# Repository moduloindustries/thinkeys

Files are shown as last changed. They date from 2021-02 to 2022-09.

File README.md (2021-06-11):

View this project on [CADLAB.io](https://cadlab.io/project/24445). 

ThinKeys
========
Split ortholinear custom replacement keyboard with TrackPoint for ThinkPad laptops.

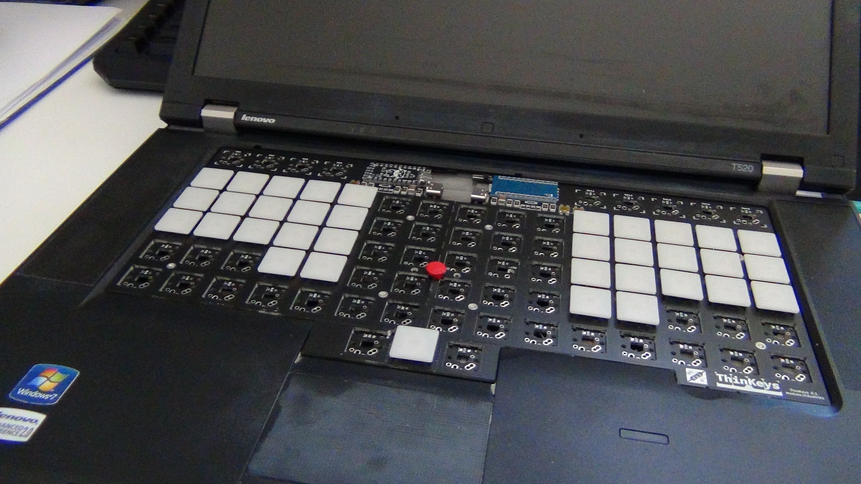
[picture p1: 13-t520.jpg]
in t520

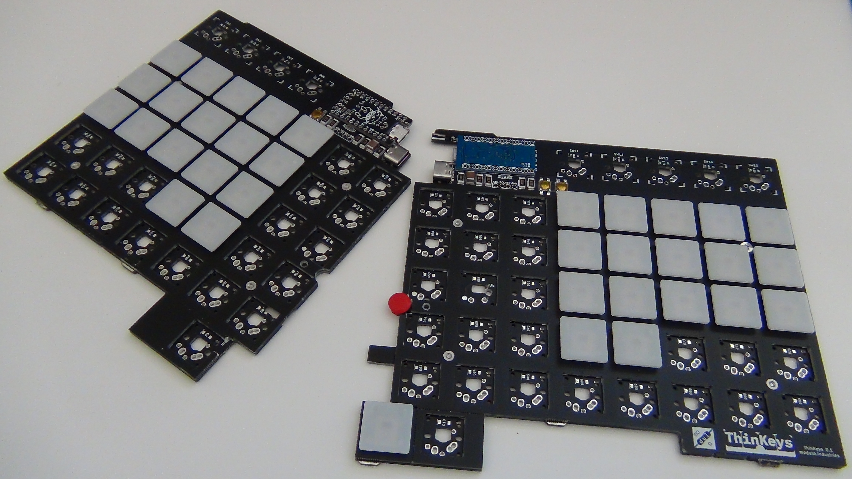
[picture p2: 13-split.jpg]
split


Layout can be mapped as desired with QMK.

Other physical layouts will be offered if there is enough demand for them.

Videos
------
- [Playlist (YouTube)](https://www.youtube.com/playlist?list=PLA83yaoqEOKUAF3hhw5IN6eBIaD0fTjDs)

Compatibility
-------------
The first model is for Lenovo ThinkPads T410-T430, T510-T530, W510-W530, and
X220-X230 (including s, i, and t suffixed variants).

Later model support planned for X230s-X270, T431s-T450s/T440(p)-T460(p) and
beyond.

Goals
-----
- [X] TrackPoint
- [X] Split for external/desktop use (connect via USB Type-C)
- [X] Ortholinear
- [ ] ~~RGB LED Backlight (ThinkLight infeasible)~~ No backlight in the first
      version, maybe next time
- [X] USB Connection
- [X] Power Button
- [X] Socketable Pro Micro (or compatible)

Chat
----
Join via Matrix: https://matrix.to/#/!igsJfJkAlUganwyDzE:librem.one?via=librem.one

Join via Discord: https://discord.gg/MA2DBqRyEK

Low Profile Keyboards Discord: https://discord.gg/yhGEvATCFs

Pineapples
----------
Inspiration and some design from https://github.com/saoto28/pineapple60

Older models like xx20/xx30 have a lot more keyboard thickness (height?) than
newer ones like T460s/T470s, so lid closing clearance is not expected be an
issue.

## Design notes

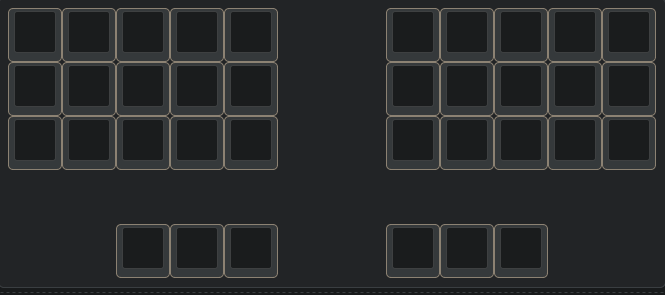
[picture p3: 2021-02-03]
23-corne.png

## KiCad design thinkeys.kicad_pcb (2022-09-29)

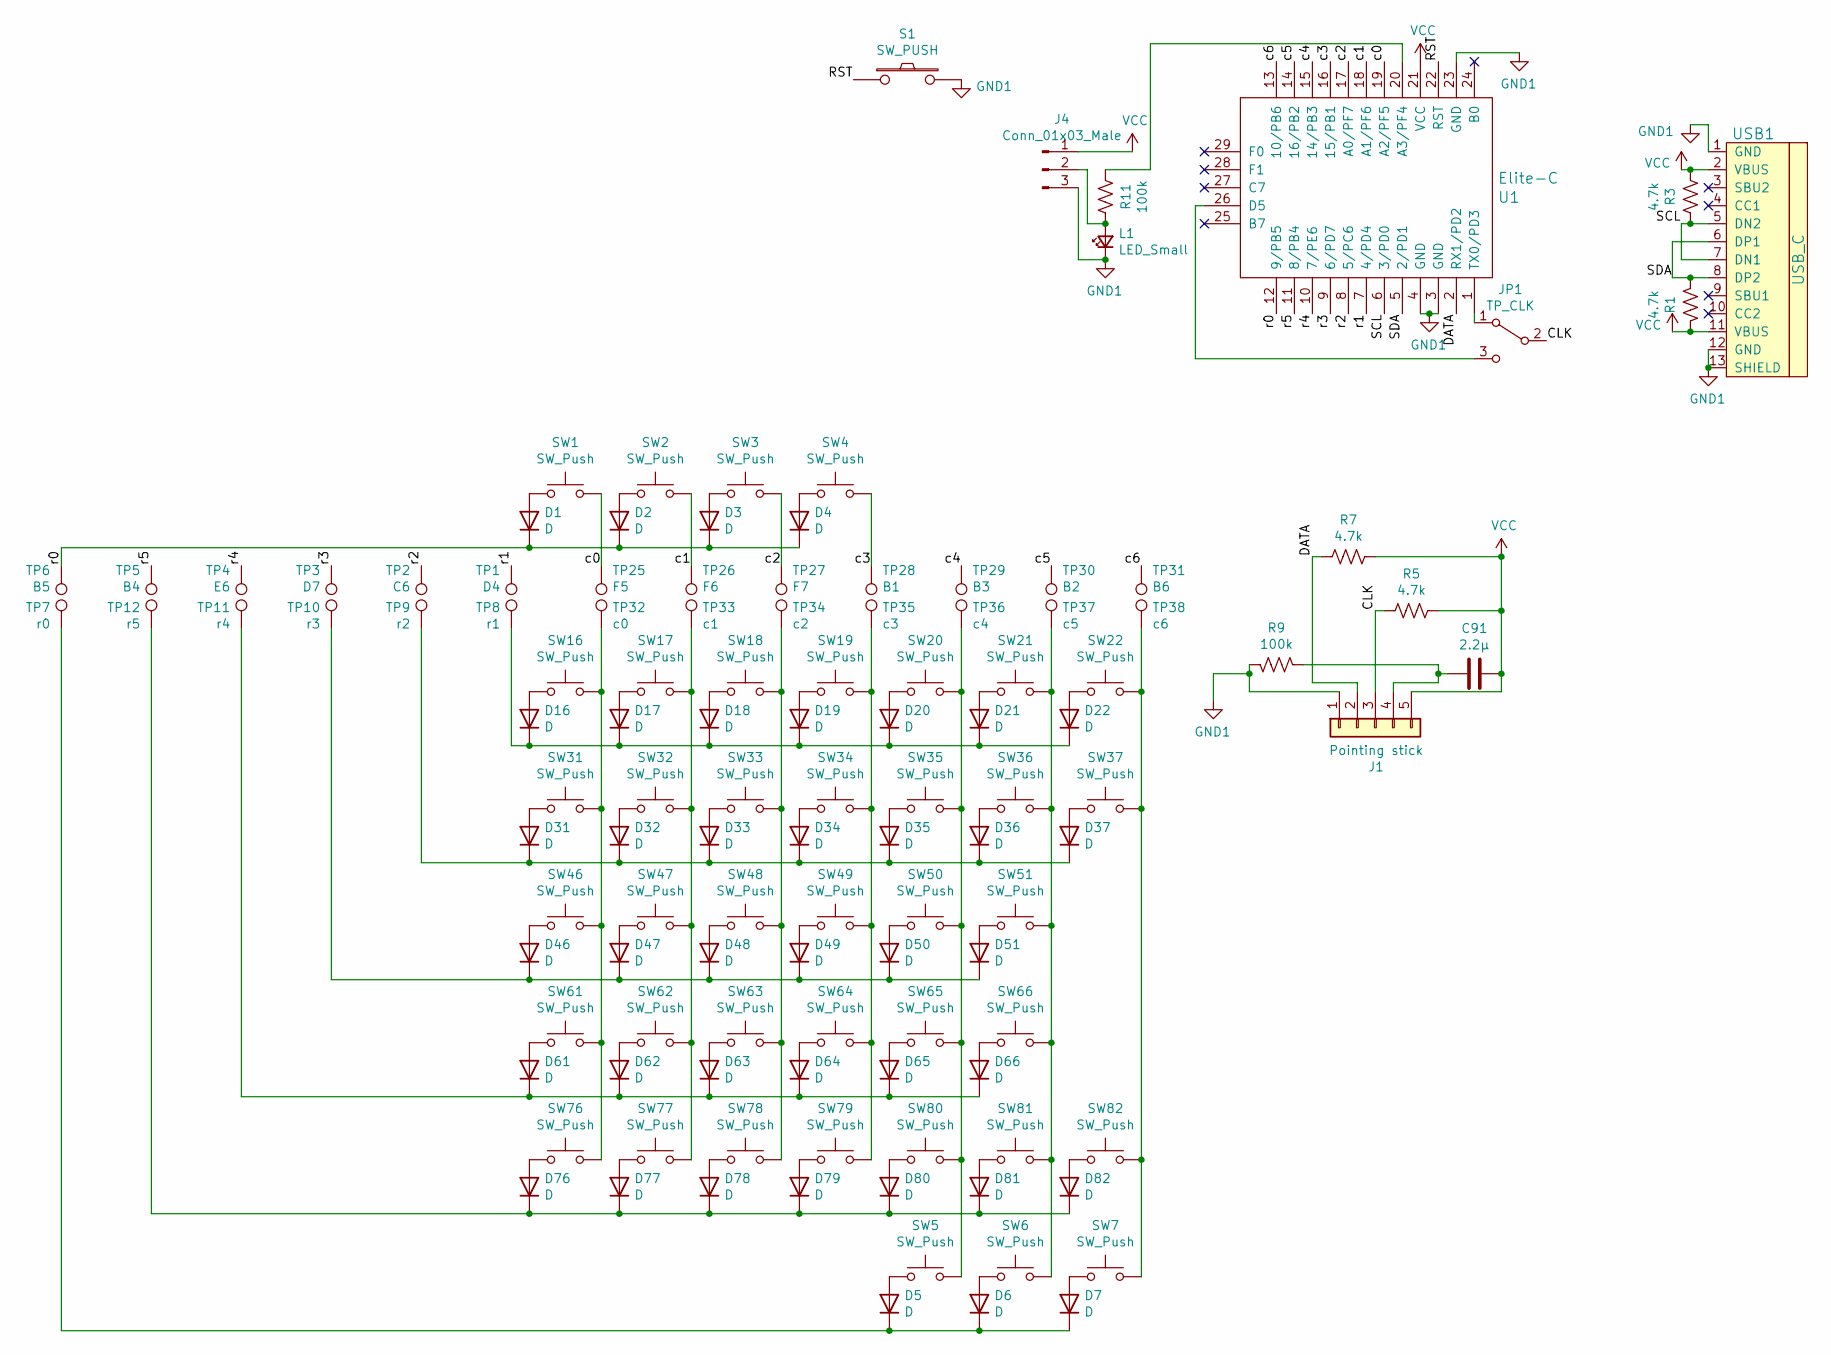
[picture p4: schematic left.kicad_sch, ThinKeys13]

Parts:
C91: 2.2µ; C_1206_3216Metric_Pad1.33x1.80mm_HandSolder; LCSC Part C50254
D1, D2, D3, D4, D5, D6, D7, D16, D17, D18, D19, D20, D21, D22, D31, D32, D33, D34, D35, D36, D37, D46, D47, D48, D49, D50, D51, D61, D62, D63, D64, D65, D66, D76, D77, D78, D79, D80, D81, D82: D; D_SOD-123; LCSC Part C64898
J1: Pointing stick; SK8707-01
J4: Conn_01x03_Male; PinHeader_1x03_P2.00mm_Vertical_SMD_Pin1Left
JP1: TP_CLK; SolderJumper-3_P1.3mm_Open_RoundedPad1.0x1.5mm_NumberLabels
L1: LED_Small; LED_0805_2012Metric_Castellated; LCSC Part C72043
R1, R3, R5, R7: 4.7k; R_1206_3216Metric_Pad1.30x1.75mm_HandSolder; LCSC Part C17936
R9: 100k; R_1206_3216Metric_Pad1.30x1.75mm_HandSolder; LCSC Part C17900
R11: 100k; R_1206_3216Metric_Pad1.30x1.75mm_HandSolder; LCSC Part C17936
S1: SW_PUSH; SW_SPST_EVQQ2; LCSC Part C713483
SW1, SW2, SW3, SW4, SW5, SW6, SW7, SW16, SW17, SW18, SW19, SW20, SW21, SW22, SW31, SW32, SW33, SW34, SW35, SW36, SW37, SW46, SW47, SW48, SW49, SW50, SW51, SW61, SW62, SW63, SW64, SW65, SW66, SW76, SW77, SW78, SW79, SW80, SW81, SW82: SW_Push; SW_MX-ALPS-ChocV1_V2-X-PG1280_PCB
TP1: D4; SMDPad_4.0x2.0mm
TP2: C6; SMDPad_4.0x2.0mm
TP3: D7; SMDPad_4.0x2.0mm
TP4: E6; SMDPad_4.0x2.0mm
TP5: B4; SMDPad_4.0x2.0mm
TP6: B5; SMDPad_4.0x2.0mm
TP7: r0; THTPad_4.0x4.0mm_Drill2.0mm
TP8: r1; THTPad_4.0x4.0mm_Drill2.0mm
TP9: r2; THTPad_4.0x4.0mm_Drill2.0mm
TP10: r3; THTPad_4.0x4.0mm_Drill2.0mm
TP11: r4; THTPad_4.0x4.0mm_Drill2.0mm
TP12: r5; THTPad_4.0x4.0mm_Drill2.0mm
TP25: F5; SMDPad_4.0x2.0mm
TP26: F6; SMDPad_4.0x2.0mm
TP27: F7; SMDPad_4.0x2.0mm
TP28: B1; SMDPad_4.0x2.0mm
TP29: B3; SMDPad_4.0x2.0mm
TP30: B2; SMDPad_4.0x2.0mm
TP31: B6; SMDPad_4.0x2.0mm
TP32: c0; THTPad_4.0x4.0mm_Drill2.0mm
TP33: c1; THTPad_4.0x4.0mm_Drill2.0mm
TP34: c2; THTPad_4.0x4.0mm_Drill2.0mm
TP35: c3; THTPad_4.0x4.0mm_Drill2.0mm
TP36: c4; THTPad_4.0x4.0mm_Drill2.0mm
TP37: c5; THTPad_4.0x4.0mm_Drill2.0mm
TP38: c6; THTPad_4.0x4.0mm_Drill2.0mm
U1: Elite-C
USB1: USB_C; HRO-TYPE-C-31-M-12; LCSC Part C165948

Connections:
/left/CLK: J1.3, JP1.2 (B), R5.1
/left/DATA: J1.2, R7.1, U1.2 (RX1/PD2)
/left/RST: S1.1, U1.22 (RST)
/left/SCL: R3.1, U1.6 (3/PD0), USB1.5 (DN2), USB1.7 (DN1)
/left/SDA: R1.1, U1.5 (2/PD1), USB1.6 (DP1), USB1.8 (DP2)
/left/c0: SW1.2, TP25.1, U1.19 (A2/PF5)
/left/c1: SW2.2, TP26.1, U1.18 (A1/PF6)
/left/c2: SW3.2, TP27.1, U1.17 (A0/PF7)
/left/c3: SW4.2, TP28.1, U1.16 (15/PB1)
/left/c4: TP29.1, U1.15 (14/PB3)
/left/c5: TP30.1, U1.14 (16/PB2)
/left/c6: TP31.1, U1.13 (10/PB6)
/left/r0: D1.1 (K), D2.1 (K), D3.1 (K), D4.1 (K), TP6.1, U1.12 (9/PB5)
/left/r1: TP1.1, U1.7 (4/PD4)
/left/r2: TP2.1, U1.8 (5/PC6)
/left/r3: TP3.1, U1.9 (6/PD7)
/left/r4: TP4.1, U1.10 (7/PE6)
/left/r5: TP5.1, U1.11 (8/PB4)
GND1: J1.1, J4.3, L1.1 (K), R9.2, S1.2, U1.3 (GND), U1.4 (GND), U1.23 (GND), USB1.1 (GND), USB1.12 (GND), USB1.13 (SHIELD)
unnamed: C91.1, J1.4, R9.1
unnamed: D1.2 (A), SW1.1
unnamed: D2.2 (A), SW2.1
unnamed: D3.2 (A), SW3.1
unnamed: D4.2 (A), SW4.1
unnamed: D5.1 (K), D6.1 (K), D7.1 (K), TP7.1
unnamed: D5.2 (A), SW5.1
unnamed: D6.2 (A), SW6.1
unnamed: D7.2 (A), SW7.1
unnamed: D16.1 (K), D17.1 (K), D18.1 (K), D19.1 (K), D20.1 (K), D21.1 (K), D22.1 (K), TP8.1
unnamed: D16.2 (A), SW16.1
unnamed: D17.2 (A), SW17.1
unnamed: D18.2 (A), SW18.1
unnamed: D19.2 (A), SW19.1
unnamed: D20.2 (A), SW20.1
unnamed: D21.2 (A), SW21.1
unnamed: D22.2 (A), SW22.1
unnamed: D31.1 (K), D32.1 (K), D33.1 (K), D34.1 (K), D35.1 (K), D36.1 (K), D37.1 (K), TP9.1
unnamed: D31.2 (A), SW31.1
unnamed: D32.2 (A), SW32.1
unnamed: D33.2 (A), SW33.1
unnamed: D34.2 (A), SW34.1
unnamed: D35.2 (A), SW35.1
unnamed: D36.2 (A), SW36.1
unnamed: D37.2 (A), SW37.1
unnamed: D46.1 (K), D47.1 (K), D48.1 (K), D49.1 (K), D50.1 (K), D51.1 (K), TP10.1
unnamed: D46.2 (A), SW46.1
unnamed: D47.2 (A), SW47.1
unnamed: D48.2 (A), SW48.1
unnamed: D49.2 (A), SW49.1
unnamed: D50.2 (A), SW50.1
unnamed: D51.2 (A), SW51.1
unnamed: D61.1 (K), D62.1 (K), D63.1 (K), D64.1 (K), D65.1 (K), D66.1 (K), TP11.1
unnamed: D61.2 (A), SW61.1
unnamed: D62.2 (A), SW62.1
unnamed: D63.2 (A), SW63.1
unnamed: D64.2 (A), SW64.1
unnamed: D65.2 (A), SW65.1
unnamed: D66.2 (A), SW66.1
unnamed: D76.1 (K), D77.1 (K), D78.1 (K), D79.1 (K), D80.1 (K), D81.1 (K), D82.1 (K), TP12.1
unnamed: D76.2 (A), SW76.1
unnamed: D77.2 (A), SW77.1
unnamed: D78.2 (A), SW78.1
unnamed: D79.2 (A), SW79.1
unnamed: D80.2 (A), SW80.1
unnamed: D81.2 (A), SW81.1
unnamed: D82.2 (A), SW82.1
unnamed: J4.2, L1.2 (A), R11.2
unnamed: JP1.1 (A), U1.1 (TX0/PD3)
unnamed: JP1.3 (C), U1.26 (D5)
unnamed: R11.1, U1.20 (A3/PF4)
unnamed: SW16.2, SW31.2, SW46.2, SW61.2, SW76.2, TP32.1
unnamed: SW17.2, SW32.2, SW47.2, SW62.2, SW77.2, TP33.1
unnamed: SW18.2, SW33.2, SW48.2, SW63.2, SW78.2, TP34.1
unnamed: SW19.2, SW34.2, SW49.2, SW64.2, SW79.2, TP35.1
unnamed: SW5.2, SW20.2, SW35.2, SW50.2, SW65.2, SW80.2, TP36.1
unnamed: SW6.2, SW21.2, SW36.2, SW51.2, SW66.2, SW81.2, TP37.1
unnamed: SW7.2, SW22.2, SW37.2, SW82.2, TP38.1
VCC: C91.2, J1.5, J4.1, R1.2, R3.2, R5.2, R7.2, U1.21 (VCC), USB1.2 (VBUS), USB1.11 (VBUS)

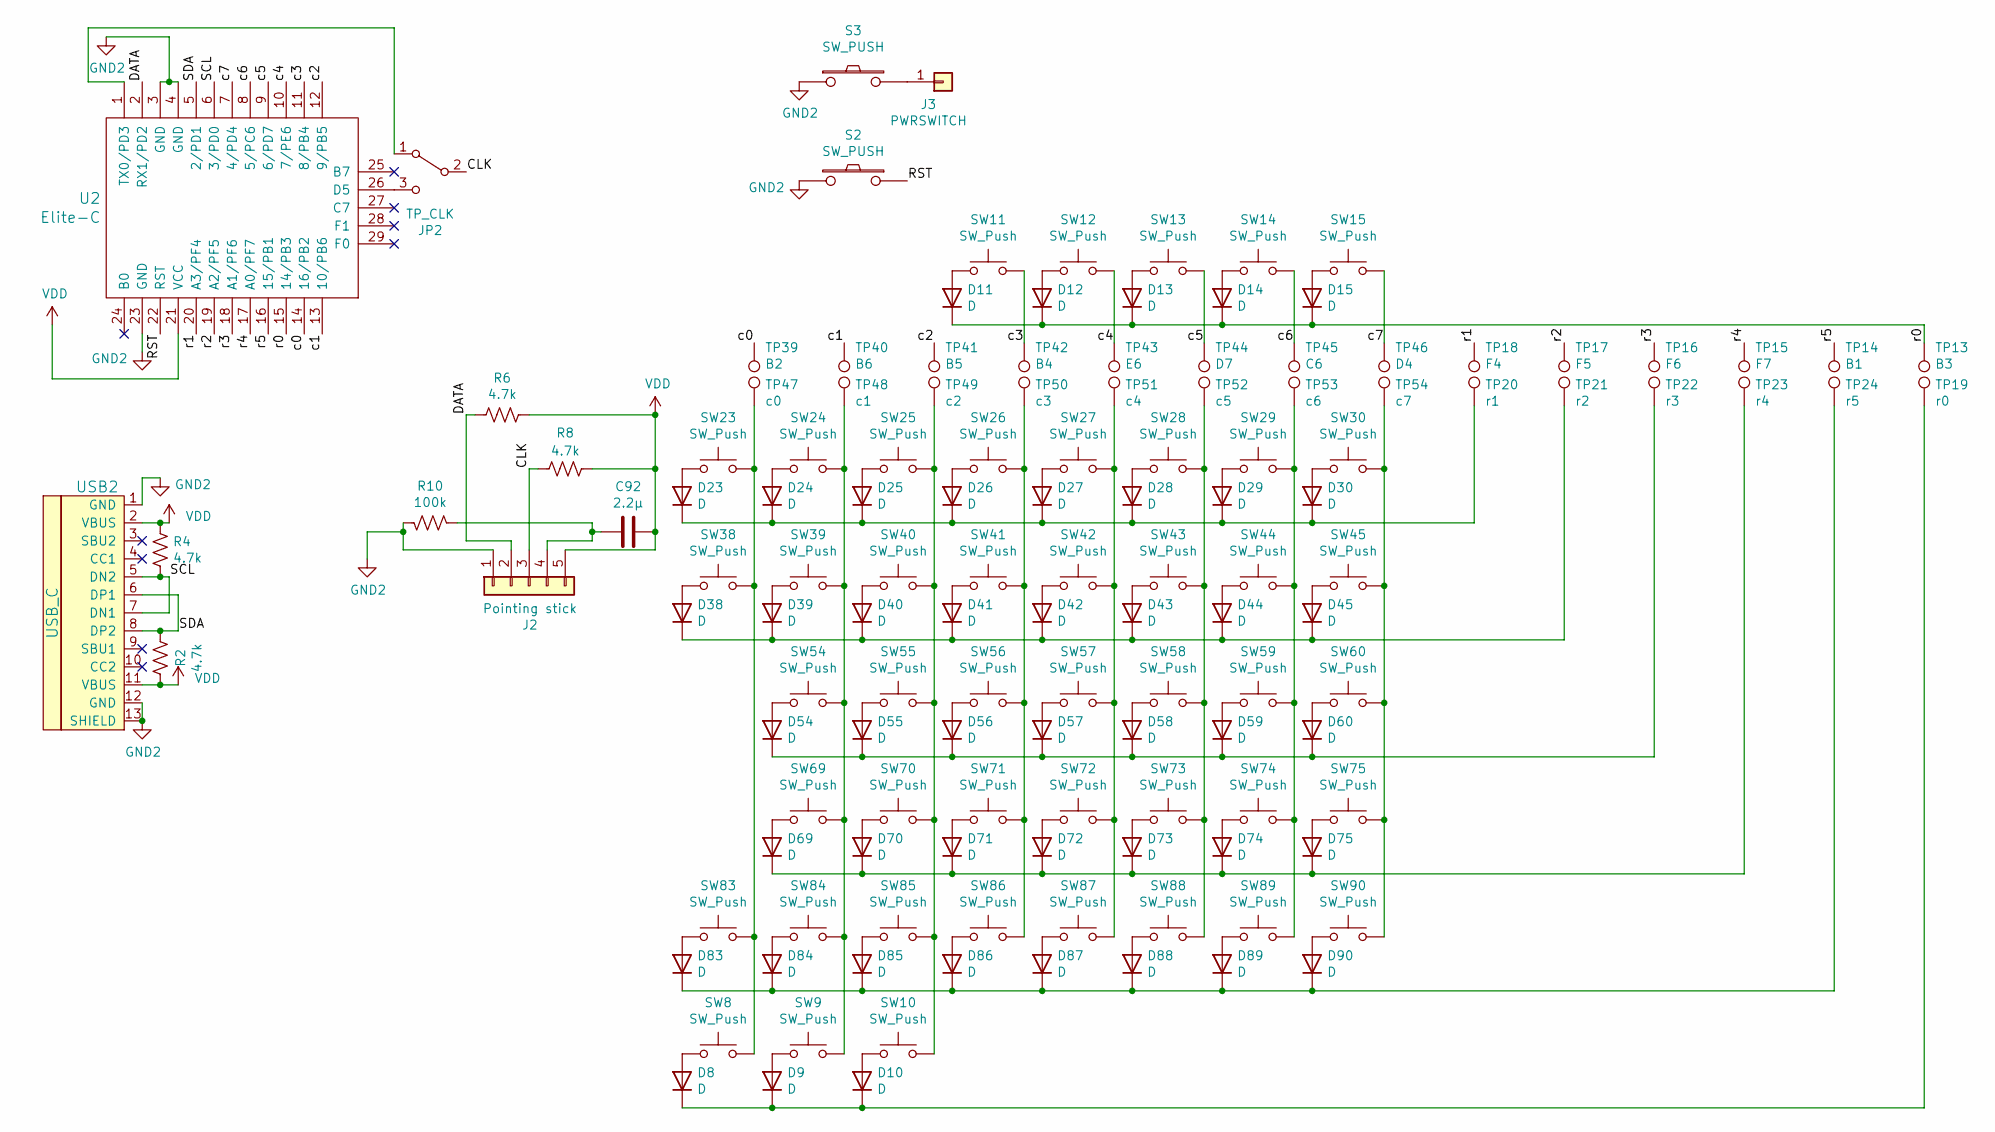
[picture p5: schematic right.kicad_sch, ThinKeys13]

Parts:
C92: 2.2µ; C_1206_3216Metric_Pad1.33x1.80mm_HandSolder; LCSC Part C50254
D8, D9, D10, D11, D12, D13, D14, D15, D23, D24, D25, D26, D27, D28, D29, D30, D38, D39, D40, D41, D42, D43, D44, D45, D54, D55, D56, D57, D58, D59, D60, D69, D70, D71, D72, D73, D74, D75, D83, D84, D85, D86, D87, D88, D89, D90: D; D_SOD-123; LCSC Part C64898
J2: Pointing stick; SK8707-01
J3: PWRSWITCH; PinHeader_1x01_P2.54mm_Horizontal
JP2: TP_CLK; SolderJumper-3_P1.3mm_Open_RoundedPad1.0x1.5mm_NumberLabels
R2, R4, R6, R8: 4.7k; R_1206_3216Metric_Pad1.30x1.75mm_HandSolder; LCSC Part C17936
R10: 100k; R_1206_3216Metric_Pad1.30x1.75mm_HandSolder; LCSC Part C17900
S2, S3: SW_PUSH; SW_SPST_EVQQ2; LCSC Part C713483
SW8, SW9, SW10, SW11, SW12, SW13, SW14, SW15, SW23, SW24, SW25, SW26, SW27, SW28, SW29, SW30, SW38, SW39, SW40, SW41, SW42, SW43, SW44, SW45, SW54, SW55, SW56, SW57, SW58, SW59, SW60, SW69, SW70, SW71, SW72, SW73, SW74, SW75, SW83, SW84, SW85, SW86, SW87, SW88, SW89, SW90: SW_Push; SW_MX-ALPS-ChocV1_V2-X-PG1280_PCB
TP13: B3; SMDPad_4.0x2.0mm
TP14: B1; SMDPad_4.0x2.0mm
TP15: F7; SMDPad_4.0x2.0mm
TP16: F6; SMDPad_4.0x2.0mm
TP17: F5; SMDPad_4.0x2.0mm
TP18: F4; SMDPad_4.0x2.0mm
TP19: r0; THTPad_4.0x4.0mm_Drill2.0mm
TP20: r1; THTPad_4.0x4.0mm_Drill2.0mm
TP21: r2; THTPad_4.0x4.0mm_Drill2.0mm
TP22: r3; THTPad_4.0x4.0mm_Drill2.0mm
TP23: r4; THTPad_4.0x4.0mm_Drill2.0mm
TP24: r5; THTPad_4.0x4.0mm_Drill2.0mm
TP39: B2; SMDPad_4.0x2.0mm
TP40: B6; SMDPad_4.0x2.0mm
TP41: B5; SMDPad_4.0x2.0mm
TP42: B4; SMDPad_4.0x2.0mm
TP43: E6; SMDPad_4.0x2.0mm
TP44: D7; SMDPad_4.0x2.0mm
TP45: C6; SMDPad_4.0x2.0mm
TP46: D4; SMDPad_4.0x2.0mm
TP47: c0; THTPad_4.0x4.0mm_Drill2.0mm
TP48: c1; THTPad_4.0x4.0mm_Drill2.0mm
TP49: c2; THTPad_4.0x4.0mm_Drill2.0mm
TP50: c3; THTPad_4.0x4.0mm_Drill2.0mm
TP51: c4; THTPad_4.0x4.0mm_Drill2.0mm
TP52: c5; THTPad_4.0x4.0mm_Drill2.0mm
TP53: c6; THTPad_4.0x4.0mm_Drill2.0mm
TP54: c7; THTPad_4.0x4.0mm_Drill2.0mm
U2: Elite-C
USB2: USB_C; HRO-TYPE-C-31-M-12; LCSC Part C165948

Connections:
/right/CLK: J2.3, JP2.2 (B), R8.1
/right/DATA: J2.2, R6.1, U2.2 (RX1/PD2)
/right/RST: S2.1, U2.22 (RST)
/right/SCL: R4.1, U2.6 (3/PD0), USB2.5 (DN2), USB2.7 (DN1)
/right/SDA: R2.1, U2.5 (2/PD1), USB2.6 (DP1), USB2.8 (DP2)
/right/c0: TP39.1, U2.14 (16/PB2)
/right/c1: TP40.1, U2.13 (10/PB6)
/right/c2: TP41.1, U2.12 (9/PB5)
/right/c3: SW11.2, TP42.1, U2.11 (8/PB4)
/right/c4: SW12.2, TP43.1, U2.10 (7/PE6)
/right/c5: SW13.2, TP44.1, U2.9 (6/PD7)
/right/c6: SW14.2, TP45.1, U2.8 (5/PC6)
/right/c7: SW15.2, TP46.1, U2.7 (4/PD4)
/right/r0: D11.1 (K), D12.1 (K), D13.1 (K), D14.1 (K), D15.1 (K), TP13.1, U2.15 (14/PB3)
/right/r1: TP18.1, U2.20 (A3/PF4)
/right/r2: TP17.1, U2.19 (A2/PF5)
/right/r3: TP16.1, U2.18 (A1/PF6)
/right/r4: TP15.1, U2.17 (A0/PF7)
/right/r5: TP14.1, U2.16 (15/PB1)
GND2: J2.1, R10.2, S2.2, S3.1, U2.3 (GND), U2.4 (GND), U2.23 (GND), USB2.1 (GND), USB2.12 (GND), USB2.13 (SHIELD)
unnamed: C92.1, J2.4, R10.1
unnamed: D8.2 (A), SW8.1
unnamed: D9.2 (A), SW9.1
unnamed: D8.1 (K), D9.1 (K), D10.1 (K), TP19.1
unnamed: D10.2 (A), SW10.1
unnamed: D11.2 (A), SW11.1
unnamed: D12.2 (A), SW12.1
unnamed: D13.2 (A), SW13.1
unnamed: D14.2 (A), SW14.1
unnamed: D15.2 (A), SW15.1
unnamed: D23.1 (K), D24.1 (K), D25.1 (K), D26.1 (K), D27.1 (K), D28.1 (K), D29.1 (K), D30.1 (K), TP20.1
unnamed: D23.2 (A), SW23.1
unnamed: D24.2 (A), SW24.1
unnamed: D25.2 (A), SW25.1
unnamed: D26.2 (A), SW26.1
unnamed: D27.2 (A), SW27.1
unnamed: D28.2 (A), SW28.1
unnamed: D29.2 (A), SW29.1
unnamed: D30.2 (A), SW30.1
unnamed: D38.1 (K), D39.1 (K), D40.1 (K), D41.1 (K), D42.1 (K), D43.1 (K), D44.1 (K), D45.1 (K), TP21.1
unnamed: D38.2 (A), SW38.1
unnamed: D39.2 (A), SW39.1
unnamed: D40.2 (A), SW40.1
unnamed: D41.2 (A), SW41.1
unnamed: D42.2 (A), SW42.1
unnamed: D43.2 (A), SW43.1
unnamed: D44.2 (A), SW44.1
unnamed: D45.2 (A), SW45.1
unnamed: D54.1 (K), D55.1 (K), D56.1 (K), D57.1 (K), D58.1 (K), D59.1 (K), D60.1 (K), TP22.1
unnamed: D54.2 (A), SW54.1
unnamed: D55.2 (A), SW55.1
unnamed: D56.2 (A), SW56.1
unnamed: D57.2 (A), SW57.1
unnamed: D58.2 (A), SW58.1
unnamed: D59.2 (A), SW59.1
unnamed: D60.2 (A), SW60.1
unnamed: D69.1 (K), D70.1 (K), D71.1 (K), D72.1 (K), D73.1 (K), D74.1 (K), D75.1 (K), TP23.1
unnamed: D69.2 (A), SW69.1
unnamed: D70.2 (A), SW70.1
unnamed: D71.2 (A), SW71.1
unnamed: D72.2 (A), SW72.1
unnamed: D73.2 (A), SW73.1
unnamed: D74.2 (A), SW74.1
unnamed: D75.2 (A), SW75.1
unnamed: D83.1 (K), D84.1 (K), D85.1 (K), D86.1 (K), D87.1 (K), D88.1 (K), D89.1 (K), D90.1 (K), TP24.1
unnamed: D83.2 (A), SW83.1
unnamed: D84.2 (A), SW84.1
unnamed: D85.2 (A), SW85.1
unnamed: D86.2 (A), SW86.1
unnamed: D87.2 (A), SW87.1
unnamed: D88.2 (A), SW88.1
unnamed: D89.2 (A), SW89.1
unnamed: D90.2 (A), SW90.1
unnamed: J3.1, S3.2
unnamed: JP2.1 (A), U2.1 (TX0/PD3)
unnamed: JP2.3 (C), U2.26 (D5)
unnamed: SW10.2, SW25.2, SW40.2, SW55.2, SW70.2, SW85.2, TP49.1
unnamed: SW8.2, SW23.2, SW38.2, SW83.2, TP47.1
unnamed: SW9.2, SW24.2, SW39.2, SW54.2, SW69.2, SW84.2, TP48.1
unnamed: SW26.2, SW41.2, SW56.2, SW71.2, SW86.2, TP50.1
unnamed: SW27.2, SW42.2, SW57.2, SW72.2, SW87.2, TP51.1
unnamed: SW28.2, SW43.2, SW58.2, SW73.2, SW88.2, TP52.1
unnamed: SW29.2, SW44.2, SW59.2, SW74.2, SW89.2, TP53.1
unnamed: SW30.2, SW45.2, SW60.2, SW75.2, SW90.2, TP54.1
VDD: C92.2, J2.5, R2.2, R4.2, R6.2, R8.2, U2.21 (VCC), USB2.2 (VBUS), USB2.11 (VBUS)

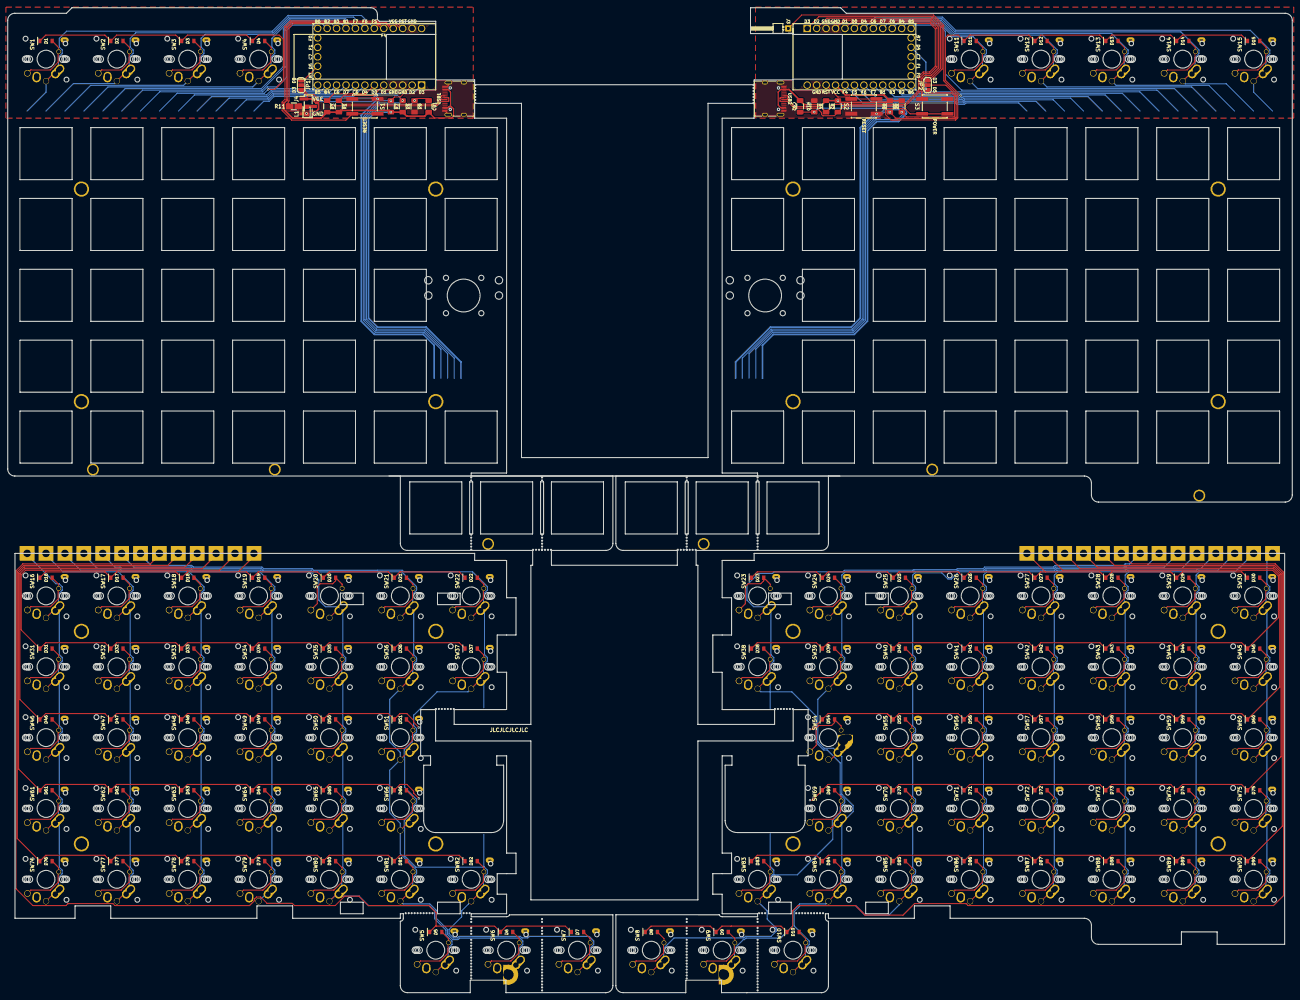
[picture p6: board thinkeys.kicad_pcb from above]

Board: 2 copper layers, 345.4 x 264.8 mm, 269 parts (0 on the bottom side), 163 nets.

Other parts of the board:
Ref**: Val**; MountingHole_3.2mm
Ref**#2, Ref**#3, Ref**#4, Ref**#5, Ref**#6, Ref**#7, Ref**#8, Ref**#9, Ref**#10, Ref**#11, Ref**#12, Ref**#13, Ref**#14, Ref**#15, Ref**#16: Val**; MountingHole_3.2mm

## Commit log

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2021-02-03 annotate schematic, add documentation
    [thinkeys.sch]
2021-02-04 add left side & trrs connection to schematic
    [thinkeys.sch]
2021-02-04 fix row numbering for split
    [thinkeys.sch]
2021-02-06 switch pro micro to use keebio lib; rm unused libs
    [thinkeys.sch]
2021-02-06 fix annotations and footprint assignments
    [thinkeys.sch]
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2021-02-06 make/use own library for TRRS
    [thinkeys.sch]
2021-02-07 center footprint; isolate mouse buttons; init pcb
    [thinkeys.kicad_pcb, thinkeys.sch]
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2021-02-07 reduce trrs diameter to 9.779mm
    [thinkeys.kicad_pcb]
2021-02-08 fix top clearance
    [thinkeys.kicad_pcb]
2021-02-08 add pointing stick, and some values, to schematic
    [thinkeys.sch]
2021-02-09 harmonize schematic; add library footprint
    [thinkeys.sch]
2021-02-10 add micro switch for pwrswitch, & placement
    [thinkeys.kicad_pcb, thinkeys.sch]
2021-02-10 make PG1353, PG1442 footprints & merge them in
    [thinkeys.kicad_pcb]
2021-02-10 add proper spacing for trackpoint buttons
    [thinkeys.kicad_pcb]
2021-02-11 rm 0.25 silk & redundant footprint pads
    [thinkeys.kicad_pcb]
2021-02-20 split schematic, add rgb leds, use elite-c pins
    [left.sch, right.sch, thinkeys.kicad_pcb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]
2021-02-21 connect gnd's, assign footprints, move right rgb
    [left.sch, right.sch]
2021-02-21 add title metadata & page format
    [left.sch, right.sch, thinkeys.kicad_pcb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]
2021-03-01 set/change footprints, add usb-c, align components
    [left.sch, right.sch, thinkeys.kicad_pcb]
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2021-03-01 flip resistors in order, place no connection flags
    [left.sch, right.sch]
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2021-03-02 reroute columns, fix/place leds, fix positions
    [left.sch, right.sch, thinkeys.kicad_pcb]
2021-03-03 add 0.215 mm track width
    [thinkeys.kicad_pcb]
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2021-03-11 move to double pcb design
    [thinkeys.kicad_pcb]
2021-03-11 put edge cuts and new footprint positions
    [thinkeys.kicad_pcb]
2021-03-11 use correct ground symbol on right side usb-c
    [right.sch, thinkeys.kicad_pcb]
2021-03-11 re-add missing diode 76
    [thinkeys.kicad_pcb]
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2021-03-20 caps to leds; route most traces; castellate rows
    also:
    - reassign pins
    - align components
    - switch to new trackpoint footprint
    [left.sch, right.sch, thinkeys.kicad_pcb]
2021-03-20 rm rgb backlight led, castellate columns
    [left.sch, right.sch, thinkeys.kicad_pcb]
2021-03-22 pcb: new footprints & traces
    [left.sch, right.sch, thinkeys.kicad_pcb]
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2021-06-04 unpanelize, fix left vcc zone/right hole, rm slots
2021-06-04 new trackpoint footprint, silk around holes, chocs
    [thinkeys.kicad_pcb]
2021-06-05 pcb: fix trackpoint tongue and groove dimensions
    [thinkeys.kicad_pcb]
2021-06-07 pcb: sw54: reinstate choc/mx, x holes, smd spacer
    [thinkeys.kicad_pcb]
2021-06-07 pcb: shrink mcu cutout to 30x12 mm (301230 batt)
    [thinkeys.kicad_pcb]
2021-06-08 pcb: don't protrude edge cuts by 0.15mm in middle
    [thinkeys.kicad_pcb]
2021-06-08 pcb: fix right side trackpoint tongue/groove width
    [thinkeys.kicad_pcb]
2021-06-08 pcb: make mid trackpoint button slot 0.8mm/fix pos
    [thinkeys.kicad_pcb]
2021-06-08 pcb: raise outermost trackpoint buttons breakaway
    [thinkeys.kicad_pcb]
2021-06-08 pcb: fix right side mcu front label b5 orientation
    [thinkeys.kicad_pcb]
2021-06-08 pcb: introduce rounded slot corners/more top slots
    [thinkeys.kicad_pcb]
2021-06-08 minimum trace to 0.15mm, left side top B.Cu GND
    [thinkeys.kicad_pcb]
2021-06-09 pcb: shrink power button pin header through hole
    [thinkeys.kicad_pcb]
2021-06-10 pcb: fix trackpoint buttons size
    [thinkeys.kicad_pcb]
2021-06-10 pcb: corner rounding 0.95/0 mm to 1.9 mm
    [thinkeys.kicad_pcb]
2021-06-10 pcb: fix arrow cluster area size
    [thinkeys.kicad_pcb]
2021-06-10 pcb: fix minutiae
    [thinkeys.kicad_pcb]
2021-06-12 pcb: connect top row to mcu/update sch footprints
    [left.sch, right.sch, thinkeys.kicad_pcb]
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2021-06-12 pcb: update bottom mounting holes/convert to smd
    [left.sch, right.sch, thinkeys.kicad_pcb]
2021-06-12 sch: make it look more like the boardview
    [left.sch, right.sch]
2021-06-14 sch: correct oled vcc reference
    [left.sch]
2021-06-14 switch to new footprints for switches/trackpoints
    [left.sch, right.sch, thinkeys.kicad_pcb]
2021-06-15 pcb: make j3 power button header pin smaller
    [thinkeys.kicad_pcb]
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2021-06-17 switch to matching flush top pad for bottom hole
    [left.sch, right.sch, thinkeys.kicad_pcb]
2021-06-18 pcb: fix split connection usb location
    [thinkeys.kicad_pcb]
2021-06-20 redo top positions, routing & footprints
    [left.sch, right.sch, thinkeys.kicad_pcb]
2021-06-22 pcb: finish routing new top area
    [thinkeys.kicad_pcb]
2021-06-23 pcb: add magnetic tenting kit support
    [thinkeys.kicad_pcb]
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2021-06-23 fix left side row pin positions
    [left.sch, thinkeys.kicad_pcb]
2021-06-24 pcb: update fill & fix left side jumper label
    [thinkeys.kicad_pcb]
2021-06-27 make changes for bom output
    [right.sch, thinkeys.kicad_pcb]
2021-06-29 pcb: new tab footprint
    [thinkeys.kicad_pcb]
2021-06-29 pcb: hole update: new mousebites, plate mountholes
    [thinkeys.kicad_pcb]
2021-07-03 pcb: update switch footprint, prune copper fills
    [thinkeys.kicad_pcb]
2021-07-03 pcb: remove labels troublesome for panelizing time
    [thinkeys.kicad_pcb]
2021-07-03 pcb: flip right side labels for panelization
    [thinkeys.kicad_pcb]
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2021-07-05 switch to 1206 compoments and add lcsc part number
    [left.sch, right.sch, thinkeys.kicad_pcb]
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2021-07-05 pcb: fix text and footprint location
    [thinkeys.kicad_pcb]
2021-07-05 prevent text issues, new footprints/3dmodels
    [thinkeys.kicad_pcb]
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2021-07-09 pcb: extend usb port, adjust copper to match
    [thinkeys.kicad_pcb]
2021-07-09 move push button references to S**, text to side
    [left.sch, right.sch, thinkeys.kicad_pcb]
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2021-07-10 pcb: add RESET/POWER label
    [thinkeys.kicad_pcb]
2021-08-16 preparing for production
    - flip right side boards upside down
    - move right side towards the lest
    - move bottom towards the top
    - add mouse bites and rails
    - new detachable tabs implementation
    - move logos
    - adjust screw mount holes
    [thinkeys.kicad_pcb]
2021-08-16 ground pad, led resistor, PTH screw mount holes
    [left.sch, right.sch, thinkeys.kicad_pcb]
2021-08-21 fix bottom piece usb area cutouts to match the top
    [thinkeys.kicad_pcb]
2021-09-29 pcb: add eco1.user lines for export to svg cutouts
    [thinkeys.kicad_pcb]
2021-09-29 pcb: flip right side labels: face more toward user
    [thinkeys.kicad_pcb]
2021-10-01 pcb: shrink jumper hole size, make it more square
    [thinkeys.kicad_pcb]
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2022-03-21 pcb: update footprints, fix panelization cuts
    [thinkeys.kicad_pcb]
2022-03-21 pcb: move bottom right up, repanelize simply, jlc
    [thinkeys.kicad_pcb]
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2022-05-24 pcb: fix top middle cutout
    [thinkeys.kicad_pcb]
2022-05-24 pcb: reduce overall width from 287.8mm to 287.5mm
    [thinkeys.kicad_pcb]
2022-05-24 pcb: breakaway tab arm clear hole by 2mm: jlc spec
    [thinkeys.kicad_pcb]
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2022-05-25 pcb: left side F4 label, more track-edge clearance
    [thinkeys.kicad_pcb]
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2022-06-14 pcb: add jlc specify order number location text
    [thinkeys.kicad_pcb]
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2022-08-31 pcb: width revert to 287.8 mm
    [thinkeys.kicad_pcb]
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2022-09-21 Revert "pcb: convert joint between top/bottom to v-score"
    This reverts commit c1ad268ccf8d00d990148b393a468e0298c2c4ef.
    [thinkeys.kicad_pcb]
2022-09-22 pcb: wide top v-cut for production (less fragile)
    [thinkeys.kicad_pcb]
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2022-09-23 pcb: top: add helper lines for breakaway keys
    [thinkeys.kicad_pcb]
2022-09-29 pcb: move v-cut text to avoid appearing when fab'd
    [thinkeys.kicad_pcb]
